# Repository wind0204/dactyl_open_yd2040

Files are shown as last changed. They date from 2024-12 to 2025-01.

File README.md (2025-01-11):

# Dactyl Open - YD2040
I've built a Dactyl Pivot - Open with bigger build, movable thumb racks, and bolt-screw guides for the tenting feature.
and thought I might as well share some of the details on the internet.

The MCUs I used was good value, I guess. I don't have electronic knowledge to really evaluate it well. its name was YD-2040 V1.1;
And the firmware I used was [qmk](https://github.com/qmk/qmk_firmware)

[YD-2040-2022-V1.1-SCH.pdf](https://github.com/user-attachments/files/18221666/YD-2040-2022-V1.1-SCH.pdf)
YD-2040-2022-V1 1-pinout
rough_sketch Warning: The BAT54C is very tiny. I somehow managed to pull it off without a proper magnifier and holding the board well.
[pictures and some backstories](https://newsie.social/@Dewry/113452166034299283)

Most of the inspiration and resources came from [this](https://www.printables.com/model/102789-dactyl-flex-w-threaded-tenting), I borrowed a couple of 3d models from it and I also built a few other 3d models via [Dactyl-Pivot](https://github.com/chenfucn/dactyl-pivot) with a bit of modification and then carved them all to attach different parts like the RJ10 module, [Altana](https://github.com/swanmatch/MxLEDBitPCB), the rotary encoder and YD2040.

A couple of keycaps brush against a neighbor keycap very lightly but that is a negligible issue. some tileboards had to be shaved cleanly to remove the protruding remnant of bridges.
One tileboard on each thumb rack had to be ground on two sides; One side to make space for the parts of nylon prints where they're fastened by a bolt, and the other side to make space for a neighbor tileboard. In the picture below you can see that I made a mistake not counting into account that it had to be inverse from the opposite hand and then ground another side to correct the mistake:
not_three_sides_but_just_two

On qmk firmware, I made the keyboard emit a blue animated light on the right half whenever numpad is not being a numpad (numlock is off), and a green animated light on the left half whenever capslock is on using the single WS2812 on YD2040 V1.1; I also made the keyboard write high on the blue LED on the left YD2040 whenever SECOND_LAYER is active and on the right YD2040 whenever NKRO is off.

The minimum cost for such a project without taking into consideration the tools like solder, multimeter, crimper, etc.: https://docs.google.com/spreadsheets/d/1aFUHoXlercC7e-SuZfpWUTReEQ5fsc-MYpa9vlSZMmo/edit?usp=sharing

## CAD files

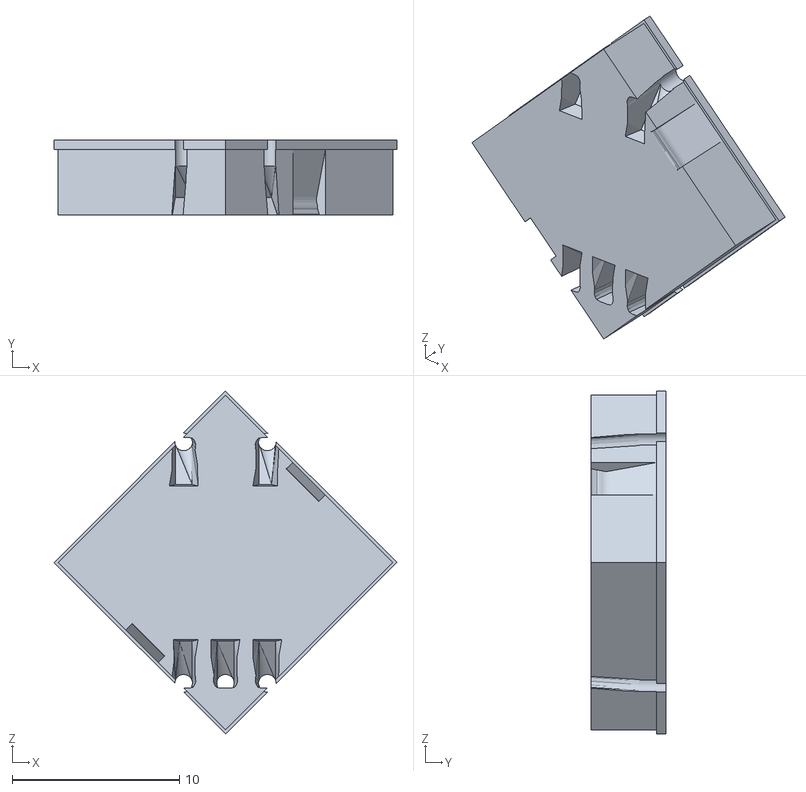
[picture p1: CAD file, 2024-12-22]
3d_models/mx_switch_adapter-pec11r-4.stl
20.5 x 4.50 x 20.5

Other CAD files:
3d_models/Tent-base-right-V204-long.blend
3d_models/Tent-base-right-V204-longer.blend
3d_models/Tent-base-right-V204-medium.blend
3d_models/Tent-control-arm-V203.blend
3d_models/Tent-leg-back-YD-2040-2022-left.blend
3d_models/Tent-leg-back-YD-2040-2022-right.blend
3d_models/Thumb-Arm-A-V202.blend
3d_models/Thumb-Arm-B-V201.blend
3d_models/Thumb-Rack-right-V201.blend
3d_models/finger-plate-rack-set-right.blend
3d_models/fingers-right.blend
3d_models/thumbs-right-V2.blend

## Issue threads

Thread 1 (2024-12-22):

VBUS detection didn't work

wind0204, 2024-12-22:
USB_VBUS_PIN didn't work.
I rely on the default behavior of SPLIT_USB_DETECT because my voltage divider circuit apparently give high current to both master and slave.
I've connected a voltage divider circuit to GP22, V+(Vout) and GND.

The schematic diagram of YD2040: https://github.com/user-attachments/files/18221666/YD-2040-2022-V1.1-SCH.pdf
The sketch for my keyboard: https://github.com/user-attachments/assets/98f7b280-ba3f-4c0e-90d6-2f0516f1632d

wind0204, 2025-01-03:
The way to go: https://discord.com/channels/440868230475677696/1324838308416589950/1324846022668849214

wind0204, 2025-01-04:
The fix shown in f62b880c9ddb3aae3b5686414940ff2701b17bb2

wind0204, 2025-01-04:
The fix is shown in f62b880c9ddb3aae3b5686414940ff2701b17bb2

wind0204, 2025-01-04:
The fix is shown in f62b880c9ddb3aae3b5686414940ff2701b17bb2

wind0204, 2025-01-04:
Not planned -> Completed

wind0204, 2025-01-04:
Let me close the issue properly.

Closed 2025-01-04.

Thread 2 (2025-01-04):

`hex-m6-4-9.825 X1.1` in Tent-base-.+.blend is too small for 1172Pro (nylon) printing

wind0204, 2025-01-04:
I had to shave 4 sides out of the six sides a little bit to make it easy to plug in the hex bolt I had.

wind0204, 2025-01-11:
Hopefully fixed in 613c86cb1b1cd694a3127b0f9bb2ea5c38dab550

Closed 2025-01-11.

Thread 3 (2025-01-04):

Tent-control-arm.*.blender needs a guide for heatset insert

wind0204, 2025-01-04:
It was not easy to balance the specific heatset insert I had on top of the control arm.
It would've been much nice if there had been a slot for the insert to seat on.

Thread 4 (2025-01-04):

There should be a close-up look on the board just in case somebody would like to make a copy

wind0204, 2025-01-04:
There should be a close-up look on the board just in case somebody would like to make a copy, they can benefit from a few tips as to what to solder first.

1. Short the Schottky diode on RP2040
2. connect GP0 and the wire which in turn will get connected to the RJ10 connector CRJ029-G-TH

These two can benefit from open space while soldering.

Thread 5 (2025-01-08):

The main shaft is a bit too short in Tent-base-.+.blend

wind0204, 2025-01-08:
The main shaft in Tent-base-.+.blend should be elongated by 0.5 mm

wind0204, 2025-01-10:
80b1209b675c96f43ea0ba895a7497a288291146 hopefully fixed the issue.

Closed 2025-01-10.

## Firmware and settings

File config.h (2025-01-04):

#pragma once




/* USB Device descriptor parameter */

// QMK compiler warns that these are deprecated in favor of the usb field in info.json
// and will be removed at a later date
//#define VENDOR_ID       0x15F4  // This ID is registered for 'Computer & Entertainment, Inc.'
//#define PRODUCT_ID      0xFFFE  // Can I use `0xFFFF - 1`?
//#define DEVICE_VER      0x0001  // = 0.01



/* The key matrix */
#define NR_ROWS 6
#define NR_COLUMNS 7
//#define MATRIX_COLS NR_COLUMNS
//#define MATRIX_ROWS ( NR_ROWS * 2 )
//#define MATRIX_COL_PINS { GP10, GP7, GP6, GP5, GP4, GP3, GP2 }
//#define MATRIX_ROW_PINS { GP20, GP19, GP18, GP17, GP16, GP15 }
//#define DIODE_DIRECTION COL2ROW
// These lines have been moved to info.json



/* Handedness */
#define SPLIT_HAND_MATRIX_GRID GP17, GP2  // I wrote the row pin first because DIODE_DIRECTION is COL2ROW,
                                          // and the doc says output pin first, input pin second;
                                          // They mean that logical output pin for reading at the first element of the array,
                                          // and logical input pin for changing the flow of electric current at the second.
                                          // and they internally change the flow of electric current at the ROW of COL2ROW matrix
                                          // when they peek at an intersection for SPLIT_HAND_MATRIX_GRID
                                          // reading the change of voltage at the COL.
#define MATRIX_MASKED  // const matrix_row_t matrix_mask[] is defined in rev1.c

//#define EE_HANDS
// When EE_HANDS is defined: add '-bl uf2-split-(left)|(right)' to the command sequence for flashing.
//  qmk flash -kb handwired/wind0204/dactyl_open_yd2040 -km default -bl uf2-split-left
//  qmk flash -kb handwired/wind0204/dactyl_open_yd2040 -km default -bl uf2-split-right



/* Synchronize */

// I thought..
#define SPLIT_LED_STATE_ENABLE  // "The firmware on slave does call layer_update_kb without this"
//#undef SPLIT_LED_STATE_ENABLE  // "So it's not useful for my keyboard."
// And then one day RGB light animation stops working on slave and not defining
// CRC8_USE_TABLE stops being a charm to prevent slave from becoming unresponsive
// when master has sent an RPC; ...And commenting out #undef SPLIT_LED_STATE_ENABLE
// fixes both of the problems. I guess the bugs are coming from a hardware/soldering defect?

#define SPLIT_LAYER_STATE_ENABLE  // This won't make slave respond to led state changes and write high for the LED accordingly.
#undef SPLIT_LAYER_STATE_ENABLE  // So it's not useful my keyboard.



/* UART */
// Use UART0 for communication between the halves
#define SERIAL_USART_DRIVER SIOD0
#define SERIAL_USART_FULL_DUPLEX   // Enable full duplex operation mode.
#define SERIAL_USART_TX_PIN GP0    // USART TX pin
#define SERIAL_USART_RX_PIN GP1    // USART RX pin
//#define UART_DRIVER SIOD0
//#define UART_TX_PIN GP0
//#define UART_RX_PIN GP1



/* USB */
// Determine who is master and who is slave using a GPIO pin
// I've connected a voltage divider circuit to GP22, V+(Vout) and GND
#define USB_VBUS_PIN GP22
// XXX My voltage divider circuit experiment somehow failed!
// Use the default behavior for now.. (SPLIT_USB_DETECT)
//#define SPLIT_WATCHDOG_ENABLE
//#define SPLIT_WATCHDOG_TIMEOUT 2048


/* TRANSACTIONS */
#define SPLIT_TRANSACTION_IDS_KB RPC_ID_SHORT_CRY



/* Rotary Encoders */
// I had to remove these two lines below to avoid conflicts with auto-generated empty ENCODERS_PAD_A definition.
//#define ENCODERS_PAD_A { GP14 }
//#define ENCODERS_PAD_B { GP13 }

#define ENCODER_RESOLUTION 4



/* CRC8 */
#define CRC8_OPTIMIZE_SPEED  // Use bigger memory operands if available hoping for faster CRC runs.
#define CRC8_USE_TABLE  // This for some reason disrupted the RPC on YD2040 for a couple of days..



/* Let me try entering the bootloader by double tapping something */
#define RP2040_BOOTLOADER_DOUBLE_TAP_RESET
#define RP2040_BOOTLOADER_DOUBLE_TAP_RESET_TIMEOUT 500U
#define RP2040_BOOTLOADER_DOUBLE_TAP_RESET_LED GP25



/* RGB */
// YD-RP2040-2022 V1.1 has one WS2812, So I get 2 RGB LEDs in total from both split halves.
#define WS2812_DI_PIN GP23

// If the color is wrong I have to try other byte order for the XL-5050RGBC-WS2812B
//#define WS2812_BYTE_ORDER WS2812_BYTE_ORDER_RGB
//#define WS2812_BYTE_ORDER WS2812_BYTE_ORDER_BGR

#define RGBLIGHT_LED_COUNT 1  // one WS2812 on each YD2040
//#define RGBLED_SPLIT {1, 1}  // Reason for commenting out: This applies RGBLIGHT_SPLIT

//#define RGBLIGHT_SPLIT  // Mirror the RGBs? No thanks.
#define RGBLIGHT_LIMIT_VAL 254
#define RGBLIGHT_DEFAULT_VAL 127

// Don't turn off lights when host goes to sleep.
#undef RGBLIGHT_SLEEP

#define RGBLIGHT_HUE_STEP 32
#define RGBLIGHT_SAT_STEP 16
#define RGBLIGHT_VAL_STEP 16

// Haven't tried #0, #1, #2 but #3 looks fine.
#define RGBLIGHT_DEFAULT_MODE RGBLIGHT_MODE_BREATHING + 3
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

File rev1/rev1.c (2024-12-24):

#include "quantum.h"
#include "rgblight.h"
#include "led.h"
#include "keyboard.h"
#include "dactyl-open-yd2040.h"
#include "transactions.h"
#include <string.h>
#include <stdint.h>

#ifdef CONSOLE_ENABLE
  #include "print.h"
#endif  // CONSOLE_ENABLE

#define LIR_INTERBAL 750  // interval for the long-interval routine in milliseconds
#define TRANSACTION_INTERVAL 256

// Mask out handedness diode to prevent it
// from keeping the keyboard awake.
const matrix_row_t matrix_mask[] = {
  0b01111111,
  0b01111111,
  0b01111111,
  0b00111111,
  0b01111111,
  0b01110000,
  0b01111111,
  0b01111111,
  0b01111111,
  0b00111111,
  0b01111111,
  0b01110000,
};



//void init_dactyl_yd2040( void );
void refresh_system_led_states( led_t led_state );
void refresh_nkro_state( uint16_t nkro_state );
void refresh_2nd_layer_indicator( uint8_t is_2nd_layer_on );



static uint8_t should_send_msg[2];
static uint8_t last_state_2nd_layer;

void short_cry_handler(uint8_t in_buflen, const void* in_data, uint8_t out_buflen, void* out_data) {
  const struct short_cry_m2s *m2s = (const struct short_cry_m2s*)in_data;
  struct short_cry_s2m *s2m = (typeof(s2m))out_data;
  
  s2m->err_no = 0;
  switch ( m2s->the_event_code ) {
    case tec_nkro_state_change:
      if ( is_keyboard_left() ) {
        s2m->err_no = err_not_my_business;
        break;
      }
      refresh_nkro_state( m2s->the_value );
      break;
    case tec_2nd_layer:
      refresh_2nd_layer_indicator( m2s->the_value );
      break;
    //case tec_handshake:
    //  init_dactyl_yd2040();
    //  break;
    default:
      s2m->err_no = err_unknown;
  }
}




void keyboard_pre_init_kb( void ) {
  memset(should_send_msg, 0, sizeof(should_send_msg));
}

void keyboard_post_init_kb( void ) {
  #ifdef CONSOLE_ENABLE
  debug_enable = true;
  dprintf("{Dactyl Pivot - Open} keyboard_post_init_kb\n");
  #endif // CONSOLE_ENABLE

  // Use the blue LED on yd2040 as an indicator. (Left: SECOND_LAYER,  Right: NKRO)
  gpio_set_pin_output(GP25);
  gpio_write_pin_low(GP25);

  refresh_system_led_states( host_keyboard_led_state() );

  transaction_register_rpc(RPC_ID_SHORT_CRY, short_cry_handler);

  keyboard_post_init_user();
}



void refresh_nkro_state( uint16_t nkro_state ) {
  #ifdef CONSOLE_ENABLE
  dprintf("{Dactyl Pivot - Open} refresh_nkro_state\n");
  #endif // CONSOLE_ENABLE

  // light up the led when NKRO is off
  if ( nkro_state )
    gpio_write_pin_low(GP25);
  else
    gpio_write_pin_high(GP25);
}



bool process_record_kb(uint16_t keycode, keyrecord_t *record) {
  switch (keycode) {
    case NK_TOGG:
      // Don't do anything extra when the key is released.
      if (!record->event.pressed)
        return true;

      // NKRO state indicator is on the right half.
      if ( is_keyboard_left() ) {
        should_send_msg[tec_nkro_state_change - 1] = -1;
        return true;
      }

      refresh_nkro_state( (uint16_t) keymap_config.nkro );
      return true;

    default:
      return true; // Process all other keycodes normally
  }
}




void refresh_2nd_layer_indicator( uint8_t is_2nd_layer_on ) {
  static uint8_t was_2nd_layer_on = 0;
  // The indicator for SECOND_LAYER is on the left half.
  if ( !is_keyboard_left() ) {

    // No need to share other layers' states but SECOND_LAYER's
    if ( is_2nd_layer_on == was_2nd_layer_on )
      return;

    should_send_msg[tec_2nd_layer - 1] = -1;
    last_state_2nd_layer = is_2nd_layer_on;
    
    was_2nd_layer_on = is_2nd_layer_on;
    return;
  }


  // The simple code for the left half goes like this:
  if ( is_2nd_layer_on )
    gpio_write_pin_high(GP25);
  else
    gpio_write_pin_low(GP25);

  was_2nd_layer_on = is_2nd_layer_on;
}

layer_state_t layer_state_set_kb(layer_state_t state) {
  #ifdef CONSOLE_ENABLE
  dprintf("{Dactyl Pivot - Open} layer_state_set_kb(\n"
      "\tlayer_state_t state = %x\n)\n", state);
  //dprintf("{Dactyl Pivot - Open} layer_state_t is %u bytes long.\n)\n", sizeof(state));
  // it's 2 bytes long
  #endif // CONSOLE_ENABLE

  refresh_2nd_layer_indicator( layer_state_cmp(state, SECOND_LAYER) );
  return state;
}




void refresh_system_led_states( led_t led_state ) {
  if ( is_keyboard_left() ) {
    // is it the left half?
    if ( !led_state.caps_lock ) {
      if ( rgblight_is_enabled() )
        rgblight_disable_noeeprom();
      return;
    }
    if ( !rgblight_is_enabled() )
      rgblight_enable_noeeprom();
    rgblight_sethsv_noeeprom(HSV_GREEN);

  } else {  // is it the right half?
    // Let's light up when numpad is not being a numpad
    if ( led_state.num_lock ) {
      if ( rgblight_is_enabled() )
        rgblight_disable_noeeprom();
      return;
    }

    if ( !rgblight_is_enabled() )
      rgblight_enable_noeeprom();
    rgblight_sethsv_noeeprom(HSV_BLUE);
  }
}


bool led_update_kb(led_t led_state) {
  #ifdef CONSOLE_ENABLE
  dprintf("{Dactyl Pivot - Open} led_update_kb(\n"
      "\tled_t led_state = %x\n)\n", led_state.raw);
  #endif // CONSOLE_ENABLE
  bool res = led_update_user(led_state);
  if ( res ) {
    refresh_system_led_states(led_state);
  }

//end_led_update_kb:
  return res;
}
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

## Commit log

2024-12-18 Prototype Initialization
2024-12-21 Fix the bug where slave won't utilize the blue LED
    by utilizing RPC feature.
    And refactor a bit.
    And enable debug console output.
    [config.h, rev1.c]
2024-12-22 Share the 3d models
    [Tent-base-left-V203.blend, Tent-base-right-V203.blend, Tent-control-arm-V203.blend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]
2024-12-22 Share the 3d model of rotary encoder - chrry mx adaptor
    [mx_switch_adapter-pec11r-4.stl]
2025-01-04 Other models need mirroring don't have their pair.
    [Tent-base-left-V203.blend]
2025-01-10 Elongate Tent-base-.+
    [Tent-base-right-V204-long.blend, Tent-base-right-V204-longer.blend, Tent-base-right-V204-medium.blend]
2025-01-10 Remove previous version of Tent-base-.+
    [Tent-base-right-V203.blend]
2025-01-11 Fix the bug where the hexa bolt head was too small
    [Tent-base-right-V204-long.blend, Tent-base-right-V204-longer.blend, Tent-base-right-V204-medium.blend]
2025-01-11 Update README.md
    numlock led reversed.
2025-01-26 Key rearrangement
    Add another OSL(THIRD_LAYER), another GUI, PAUS, LNG2(HANJ), SCROLL_LOCK
    Move ESC to the left side so that it's easy to press it while using a
    mouse on the right side
2026-01-18 Assign underscore and mouse buttons
